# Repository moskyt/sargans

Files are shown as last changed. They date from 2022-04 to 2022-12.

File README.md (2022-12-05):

# Zeleznicni uzel Sargans

Firmware pro nadrazi z adventniho kalendare 2022.

## Popis funkci

navestidlo - mezi ctyrmi rezimy se prepina otacenim knofliku, vypina a zapina se stiskem tehoz
*MOC NEFUNGUJE* a priznam se, ze uplne nevim proc. je to zahadne naladovy.

hodiny: normalne ukazuji hodiny (s RTC)

LED displej - ukazuje linku a destinaci po prijezdu vagonku

vnitrni osvetleni - trvale zapnute

osvetleni koleje c. 3 - prepina se zlutym tlacitkem, navic blika pri prijezdu vagonku

reproduktor - hraje pri prijezdu vagonku

### Na koleji c.1/2

je 24V indukcni civka, rozsveci se svetylka na vagoncich

### Pri prijezdu vlaku na kolej c. 3

- rozblika se osvetleni koleje
- na LED banneru se zobrazi linka / destinace
- prehraje se prislusna zeleznicni znelka (SBB, CFF, FFS, SNCF, DB) + hlaseni

### Hlaseni

Osmnact jich odpovida skutecne odjizdejicim linkam ze Sargansu, ale jinak jsou ze 2/3 smyslena, aby bylo pokazde jine. Destinace pokryvaji siroke okoli i vzdalenejsi kouty Svycarska, je tam i par mezinarodnich vlaku. Jingle na zacatku odpovida cilove destinaci, jinak by samozrejme mela byt porad jen SBB.

Na displeji se ukaze jen linka a cil (popr. jedna nacestna stanice), v hlaseni je pak trasa podrobneji.

Do hlaseni jsou prigenerovane i nejake dalsi splechty ohledne sektoru trid, restauracniho vozu, absence rodinneho vozu a podobne.

## Hardware

Arduino Nano Every (5V)
https://docs.arduino.cc/hardware/nano-every

RFID ctecka 125 kHz RDM6300
https://www.laskakit.cz/rfid-ctecka-s-antenou-125khz-em4100-rdm6300/

LED maticovy displej 32x8 MAX7219
https://www.laskakit.cz/32x8-led-matice-s-max7219-3mm/
-- nasledne vymenen za stejny, ale sestimodulovy

Indukcni smycka na svetla na vagonky
https://www.adafruit.com/product/5141

RTC hodiny DS3231
https://www.gme.cz/modul-rtc-ds323-i2c-a-32kb-flash

Hodinovy displej TM1637
https://www.laskakit.cz/hodinovy-displej-0-36--tm1637/

LED pasky u 3. koleje - dva 12V stripy zapojene do serie (!)
SQ-300 https://www.t-led.cz/p/led-pasek-vnitrni-sq3-300-7101
ovladane pres MOSFET modul IRF520
https://www.laskakit.cz/mosfet-tlacitko--irf520--24vdc-5a/

LED pasky uvnitr - opet dva 12V stripy zapojene do serie (!)
SQ-600 https://www.t-led.cz/p/led-pasek-vnitrni-sq3-600-7301
pripojene primo

RFID karty EM4100 125 kHz
https://www.laskakit.cz/rfid-em4100-125khz-neprepisovatelna-karta/

MP3 prehravac MH2024K-24SS
https://www.laskakit.cz/audio-mini-mp3-prehravac/
logika je 3v3, takze na arduino TX - mp3 RX spojeni je 1.5k rezistor
pozor, oba gnd piny musi byt propojene

Reproduktor 3W / 4R
https://www.laskakit.cz/reproduktor-3w-4-40mm/
pripojeny na SPKR1/2 piny mp3 prehravace

### Napajeni

Spinany 5/24V zdroj Meanwell RD-65B:
https://www.czech-meanwell.cz/meanwell/RD-65B-Mean-Well-Spinany-zdroj-uzavreny-dvouhladino-d2182.htm

5V - napaji primo LED, ctecku, neopixely + Arduino pres 5V pin
-- pripojeno do patice v rohu desky

24V - napaji indukcni civku a LED pasky
-- rozvedene pres mirne predimenzovane svorkovnice
-> indukcni civka
-> vnitrni LED stripy
-> mosfet pro LED strip na 3. koleji

### Pinout / zapojeni

#### Arduino Nano Every

(usb portem nahoru)
```
SCK   SPI CLK (LED CLK)         CIPO  (NC)
3V3   (NC)                      COPI  SPI COPI (LED DATA)
AREF  (NC)                      D10~  LED CS
D14   neopixel                  D9~   (NC)
D15   rotary B                  D8/SS (NC)
D16   rotary A                  D7    (NC)
D17   rotary switch             D6~   (NC)
SDA   I2C data (RTC)            D5~   (NC)
SDC   I2C clk (RTC)             D4    rfid
D20   clock-display clk         D3~   gleis 3 strip
D21   clock-display data        D2    strip yellow switch
5V    power bus +               GND   (NC)
RST   (NC)                      RST   (NC)
GND   power bus -               RX    MP3 TX
VIN   (NC)                      TX    MP3 RX+R
```

#### DFPlayer mini

(SD slotem dolu)
```
L19 VCC               x
L20 RX -> [TX]+R      x
L21 TX -> [RX]        x
L22 x                 x
L23 x                 x
L24 SPKR1             x
L25 GND               GND
L26 SPKR2             x
```

#### Speaker

L26 -> MP3 SPKR2
L27 -> MP3 SPKR1

#### RFID EM4100 RDM6300

(popiskem a antenou dolu)
```
L35 DATA -> [D4]    R35 x
L36 x               R36 VCC -> +
L37 x               R37 GND -> -
L38 x
L39 x
                    R47 ANT
                    R48 ANT
```

#### LED
(VCC,GND,DATA,CS,CLK bila,modra,cervena,zelena,cerna)
R28 VCC  -> +
R29 GND  -> -
R30 DATA -> [COPI] cervena
R31 CS   -> [D10] zelena
R32 CLK  -> [SCK] modra

#### hodinovy displej

(VCC,GND,DATA,CLK zelena,cervena,modra,cerna)

L29 VCC  -> +
L30 GND  -> -
L31 DATA -> [D21] modra
L32 CLK  -> [D20] cerna

#### MOSFET (gleis 3 strip)

zapojeny primo do patice (soucastkami dovnitr)

L40 GND -> -
L41 VCC -> +
L42 SIG -> [D3]

#### Neopixel

(VCC,DATA,GND cervena,hneda,cerna -> hneda, bila, cerna)
L50 VCC  -> +
L51 DATA -> [D14]
L52 GND  -> -

! prodluzka -- proto ty zmeny barev

#### Rotary switch
(GND,VCC,SWITCH,A,B cerna,zelena,cervena,modra,bila)

#### RTC modul

posledni dva jsou uplne nezapojene, vorsicht

GND -> -
VCC -> +
SDA -> [SDA]
SCL -> [SCL]
xxx
xxx

#### zlute tlacitko
L54 -> [D2]
L55 -> -

### Poznamky

EIC napajeci zasuvka je pripojena pres vypinac (na L zile) na vstup AC/DC zdroje.

Micro USB vyvedeny na vnejsi stenu je primo vytazeny z arduina. Asi nejlepsi napad je vypnout 5V/24V napajeni pred pripojenim USB kabelu, i kdyz je mozne, ze to neni uplne nutne. Pri vypnuti napajeni je ovsem trochu problem, ze vsechny komponenty jsou napajeny skrz Arduino, coz neni nejzdravejsi (problem je zejmena LED displej, ktery je schopen pri maximalnim rozsviceni odberu 1500 mA). Stejne tak MP3. Ale snad to neni megaproblem.

## Software

### Poznamky

nelze pouzit MD_Parola knihovnu na LED displej, bud s necim koliduje, nebo zacne prepisovat nejakou pamet, ale jakkoli 'funguje', tak zacne zpusobovat nepochopitelne problemy zabranujici nahravani sketche...

nastaveni RTC hodin neni udelane nijak chytre, v pripade potreby se provede jednorazovym odkomentovanim dvou radku v setup()

trochu zrada je, ze jak mp3, tak rfid pouzivaji uart. vzhledem k tomu, ze nejde pouzit (snadno) dva softwarove uarty najednou, je mp3 pripojeny na hw uart (piny rx+tx), rfid pak potrebuje jen rx pin a ten je SW.

### Knihovny

boards package: megaAVR

RDM6300 - bundled

MD_MAX72XX - 3.3.0

Adafruit NeoPixel - 1.10.5

TM1637 - 1.2.0

InputDebounce - 1.6.0

Rotary - 1.0.0

DS3232RTC - 2.0.1

DFPlayer Mini Mp3 by Makuna - 1.1.0

## Nadrazni hlaseni

Adresar `ansagen` obsahuje dva seznamy `departures-actual_sargans` (skutecne vlaky ze Sargansu) a `departures-extra` (vymyslene vlaky ze Sargansu, primerene zajimave trasy pro hledani na mape), coz jsou pseudoCSV ve formatu LINKA | TRASA | HLASENI | JINGLE. O dalsi postup se staraji rake tasky:

### timetable

Generuje `departures.json`, ktery obsahuje uz konkretne pripraveny 48-prvkovy dataset pro jednotlive vagonky.

Texty jsou ve variante `text` pro displej a `voice` pro text-to-speech syntetizer (format SSML).

Jingle je nazev znelky, viz `ansagen/resources/jingles/*.mp3` -- pozor, ffmpeg si s nimi neporadil, pokud to nebylo 44kHz. Ale jiste by to slo poladit, kdyby si nekdo ffmpeg poradne nastudoval...

```
  "0001": { # ID
    "train": { # oznaceni vlaku
      "text": "EC 193",
      "voice": "EuroCity 193"
    },
    "destination": { # trasa
      "text": "Memmingen, München Hbf",
      "voice": "Sankt Margarethen, Bregenz, Memmingen, Buchloe, München Hauptbahnhof"
    },
    "jingle": "db", # znelka
    "departure": [ # cas odjezdu H:M
      13,
      27
    ],
    "extras": [
      "Erste klasse Sektoren A und B, Zweite klasse sektoren B, C, D, E, F und G",
      "<lang xml:lang=\"fr-FR\">Restaurant</lang> Sektor B"
    ]
  },
```

### arduino

Generuje `sargans-arduino/destinations.h`, sadu retezcu pro LED banner.

### synth

Generuje MP3 hlaseni v adresari `ansagen/mp3`. Postup je nasledujici:
* sestaveni textu hlaseni
* synteza hlasu -- Amazon Polly (AWS)
* konverze na mp3 (soubory generovane primo polly nejak neprochazely pres ffmpeg)
* spojeni s prislusnym jinglem -- ffmpeg
* pridani reverb efektu -- ffmpeg

Je potreba mit nakonfigurovany AWS CLI, resp. vygenerovany konfigurak (pomoci `aws configure` nebo rucne).

## Jak to otevrit

1) k zakladne je pevne pripojena mala cast s napajeci zasuvkou

2) cela boudicka je pripevnena k zasuvce pouze dvema vruty zboku, jinak je to tam vlastne jen polozene -- je to ale sestavene dost na treni k tem vnejsim hranolkum podel sten, tak by to nemelo vadit

3) dreveny L-profil se zlutym tlacitkem a rotary switchem je ke stenam pripevnen opet dvema vruty

4) proskleny strop jde snadno vyndat. ano, je problem, ze az prilis snadno, drazky jsou moc hluboke, takze se to da shodit dovnitr. nejspis by stalo za to pridat nejake zajisteni na ten dil s tlacitky, ale zjistil jsem to uz moc pozde.

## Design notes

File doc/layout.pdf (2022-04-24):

# ARDUINO

5V in

USB

MP3

rotary

yellow btn

red btn

## MOSFET

## RFID

LED

neopixel

clock RFID

RTC

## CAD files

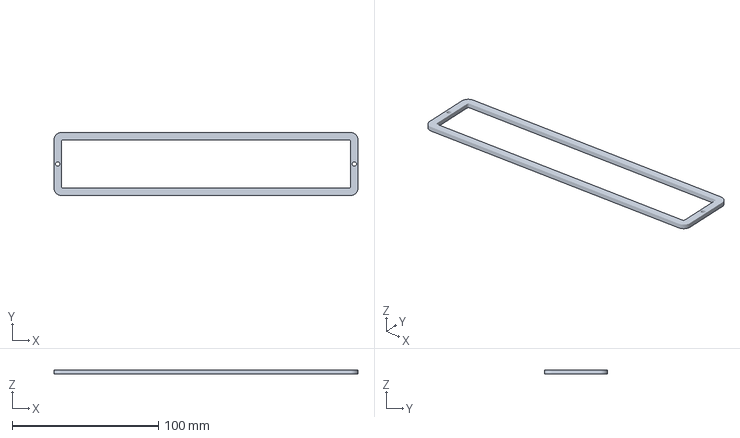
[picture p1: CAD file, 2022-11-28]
3d/led_bracket.3mf
208.0 x 43.0 x 3.00 mm

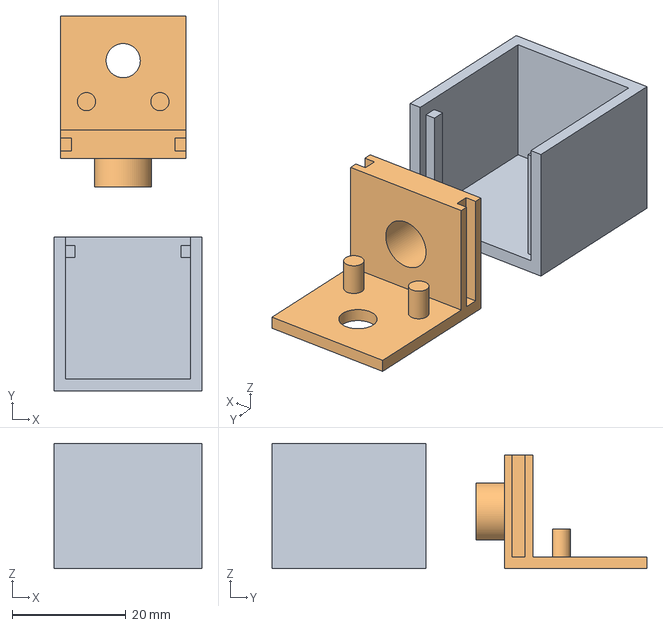
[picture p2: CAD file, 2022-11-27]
3d/semaphore.3mf
26.0 x 65.8 x 22.0 mm
semaphore.stl_1
semaphore.stl_2

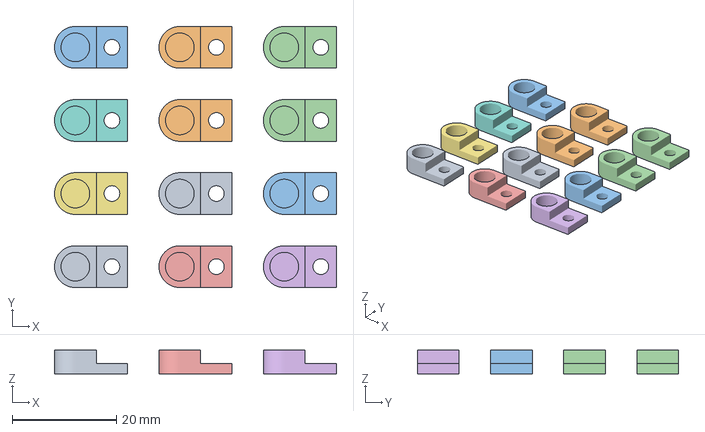
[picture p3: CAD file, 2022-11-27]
3d/led_holder.3mf
54.0 x 50.0 x 4.50 mm

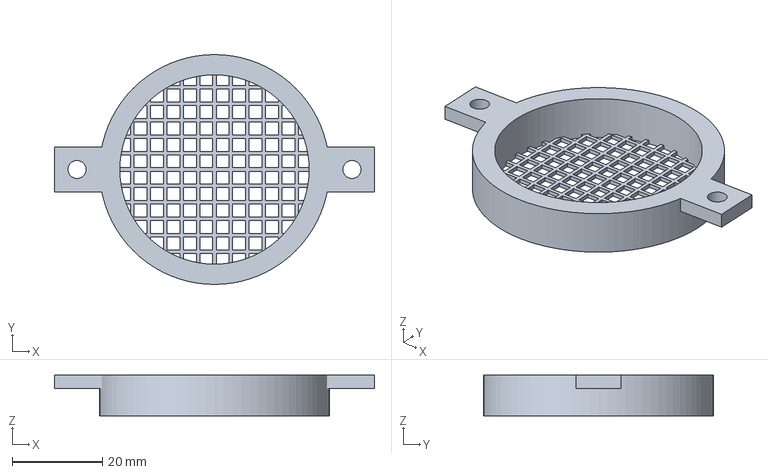
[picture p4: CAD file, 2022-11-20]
3d/speaker.3mf
71.0 x 51.0 x 9.00 mm

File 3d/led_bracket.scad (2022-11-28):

include <bosl2/std.scad>

$fn = 80;

eps = 0.1;

t = 3;
rim = 5;
inner_w = 198;
inner_h = 33;


difference() {
    cuboid([inner_w+2*rim, inner_h+2*rim, t], anchor = BOTTOM, rounding = rim, edges = [FWD+LEFT,FWD+RIGHT,BACK+LEFT,BACK+RIGHT]);
    down(eps) {
        cuboid([inner_w, inner_h, t+2*eps], anchor = BOTTOM, rounding = rim/4, edges = [FWD+LEFT,FWD+RIGHT,BACK+LEFT,BACK+RIGHT]);
        xcopies(inner_w+rim, 2)
        zcyl(l = t+2*eps, d = 3, anchor = BOTTOM);
    }
}

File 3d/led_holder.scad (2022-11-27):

include <bosl2/std.scad>

$fn = 80;

eps = 0.1;

plate_t = 2;
hole_t = 3.5;
hole_d = 5.5;
plate_d = 8;
screw_d = 3;
tab_w = 6;

difference() {
    union() {
        zcyl(plate_t/2 + hole_t, d = plate_d, anchor = BOTTOM);
        right(plate_d/4)
        cuboid([plate_d/2,plate_d,plate_t/2+hole_t],anchor=BOTTOM);
        cuboid([plate_d/2+tab_w,plate_d,plate_t],anchor=BOTTOM+LEFT);
    }
    up(plate_t/2)
    zcyl(hole_t + eps, d = hole_d, anchor = BOTTOM);
    right(plate_d/2 + tab_w/2)
    down(eps)
    zcyl(plate_t + 2*eps, d = screw_d, anchor = BOTTOM);
}

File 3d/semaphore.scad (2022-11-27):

include <bosl2/std.scad>

$fn = 80;

mx_hole_d = 3.3;
mx_hole_s = 9.5;
mx_led_d = 4.6;
mx_hole_h = 0.8;
mx_led_h = 7.3;
mx_total_h = 12.4;


eps = 0.1;

post_d = 10;
channel_d = 8;
post_h = 5;

block_w = 22;
nub_h = 5;
diode_hole_h = nub_h + 7.2;
block_t = 2;
nub_d = 3.2;
nub_spacing = 12.9;
diode_d = 6;

base_t = 5;
base_d = 20;

box_t = 2;
box_h = 25;

groove_d = 2;
groove_eps = 0.2;


back(-50)
color("red") down(base_t)
union() {
difference() {
fwd(box_t/2)
cuboid([block_w + 2*box_t,base_d + box_t, box_h+box_t], anchor=BOTTOM);
down(eps)
fwd(-eps)
cuboid([block_w,base_d, box_h], anchor=BOTTOM);
}
fwd(block_t)
up(base_t/2) {
    xcopies(block_w-groove_d+2*groove_eps,2)
    cuboid([groove_d-groove_eps,base_d,base_t/2-2*groove_eps]);
}
}

color("yellow")
difference() {
union(){
back(base_d/2) {
cuboid([block_w, block_t, box_h-base_t], anchor = BOTTOM + BACK);

up(nub_h)
fwd(block_t)
xcopies(nub_spacing,2)
ycyl(5,d=nub_d,anchor=BACK);
}
cuboid([block_w,base_d,base_t], anchor=TOP);
down(base_t)
zcyl(post_h, d=post_d, anchor=TOP);
}

up(eps)
zcyl(1000,d=channel_d,anchor=TOP);

up(diode_hole_h)
back(base_d/2)
ycyl(4*block_t,d=diode_d);

fwd(block_t+groove_eps)
down(base_t/2) {
    xcopies(block_w-groove_d+2*groove_eps,2)
    cuboid([groove_d+groove_eps,base_d+2*groove_eps,base_t/2-groove_eps]);
}


}

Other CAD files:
3d/speaker.scad
3d/led_bracket.stl
3d/led_holder.stl
3d/semaphore.stl
3d/speaker.stl

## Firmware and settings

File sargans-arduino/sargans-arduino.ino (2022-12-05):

#include <Arduino.h>
#include <MD_MAX72xx.h>
#include <TM1637Display.h>
#include <Adafruit_NeoPixel.h>
#include <InputDebounce.h>
#include <Rotary.h>
#include <DS3232RTC.h>
#include <SoftwareSerial.h>
#include <DFMiniMp3.h>

// bundled libraries
#define RDM6300_SOFTWARE_SERIAL
#include "rdm6300.h"

#include "destinations.h"

// debouncing delay for buttons in ms
const int button_debounce_delay = 20;
const int strip_blink_period = 10;
const int strip_blink_count = 10;

// led settings
#define N_LED_BLOCKS 6
#define SCROLL_DELAY 8
#define CHAR_SPACING 1

// max intensity of neopixel (signal)
const int neo_intensity = 20;

// RTC CLOCK: I2C
// LED DISPLAY: SPI (+CS)
const int pin_led_cs = 10;
// OTHER PINS
const int pin_strip_switch = 2;
const int pin_strip = 3; // pwm needed
const int pin_rdm6300 = 4;
const int pin_mp3_rx = 9;
const int pin_mp3_tx = 8;
const int pin_neopixel = 14;
const int pin_rotary_switch = 17;
const int pin_rotary_a = 15;
const int pin_rotary_b = 16;
const int pin_clockdisplay_clk = 20;
const int pin_clockdisplay_data = 21;


// RFID reader
Rdm6300 rdm6300;
// LED banner -- unfortunately, PAROLA cannot be used (insane mmry requirements)
MD_MAX72XX mx = MD_MAX72XX(MD_MAX72XX::FC16_HW, pin_led_cs, N_LED_BLOCKS);
// neopixel
Adafruit_NeoPixel pixels(1, pin_neopixel, NEO_GRB + NEO_KHZ800);
// 4-digit clock display
TM1637Display clock_display(pin_clockdisplay_clk, pin_clockdisplay_data);
// RTC
DS3232RTC rtc;

// rotary
Rotary rotary = Rotary(pin_rotary_a, pin_rotary_b);
InputDebounce rotary_button;
InputDebounce strip_button;

const int n_wagons = 48;
const uint32_t wagon_uids[n_wagons] = {
  361829,
  337311,
  343835,
  228613,
  228912,
  235002,
  250535,
  345008,
  252786,
  365067,

  355662,
  344216,
  344639,
  341953,
  339081,
  364832,
  258877,
  322125,
  203792,
  338900,

  566517,
  348127,
  329005,
  451390,
  290408,
  267758,
  186263,
  473183,
  911862,
  417940,
  
  477636,
  279181,
  // bacha prohazuju spatne nalepeny destinace 33-34, nutno otestovat
  285480, //451356,
  451356, //285480,
  293895,
  248222,
  486233,
  187191,
  342310,
  359534,
  
  273863,
  320530,
  504735,
  562113,
  538614,
  553631,
  413229,
  273606
};

#define BUF_SIZE  75
char message[BUF_SIZE] = "Sargans";

class Mp3Notify;
typedef DFMiniMp3<HardwareSerial, Mp3Notify> DfMp3;

// MP3 player notifier
class Mp3Notify {
public:
  static void OnError(DfMp3& mp3,uint16_t errorCode)
  {
    // see DfMp3_Error for code meaning
    Serial.println();
    Serial.print("MP3 com Error ");
    Serial.println(errorCode);
  }
  static void OnPlayFinished(DfMp3& mp3, DfMp3_PlaySources source, uint16_t track)
  {
    Serial.print("Play finished for #");
    Serial.println(track);
  }
  static void OnPlaySourceOnline(DfMp3& mp3,DfMp3_PlaySources source) { }
  static void OnPlaySourceInserted(DfMp3& mp3,DfMp3_PlaySources source) { }
  static void OnPlaySourceRemoved(DfMp3& mp3,DfMp3_PlaySources source) { }
};

DfMp3 mp3(Serial1);

// volume range is (0-30)
const int mp3_volume = 26;

int previous_wagon = -1;
unsigned long previous_wagon_read_time;

const int signal_mode_count = 4;
const int signal_mode_multiplier = 6;
enum signal_mode {SIG_GREEN, SIG_RED, SIG_ORANGE_BLINK, SIG_BLUE_BLINK};
signal_mode signal = SIG_RED;
bool signal_enabled = false;

bool strip_enabled = false;

int strip_blink_countdown = 0;

void setup()
{
  Serial.begin(115200);
  while (!Serial);  // wait for the serial port

  Serial.println(F("Hello from Sargans!"));

  // --- init neopixel (traffic signal)
  Serial.println(F("Init neopixel..."));
  pixels.begin();
  pixels.clear();
  pixels.setPixelColor(0, pixels.Color(0, neo_intensity, 0));
  pixels.show();

  // --- init pins not handled separately
  pinMode(pin_strip, OUTPUT);
  pinMode(pin_rdm6300, INPUT_PULLUP);

  // --- init RFID
  Serial.println(F("Init RFID..."));
  rdm6300.begin(pin_rdm6300);

  // change init signal to blue
  pixels.setPixelColor(0, pixels.Color(0, 0, neo_intensity));
  pixels.show();

  // --- init LED banner
  Serial.println(F("Init banner..."));
  mx.begin();
  mx.control(MD_MAX72XX::INTENSITY, 1); // Use a value between 0 and 15 for brightness
  printText(0, N_LED_BLOCKS-1, message);
  mx.setShiftDataInCallback(scrollDataSource);
  mx.setShiftDataOutCallback(scrollDataSink);

  // setScrollMessage(message);

  // --- init clock display
  Serial.println(F("Init clock..."));
  clock_display.setBrightness(0x02);
  uint8_t data[4];
  data[0] = clock_display.encodeDigit(9);
  data[1] = clock_display.encodeDigit(3);
  data[2] = clock_display.encodeDigit(0);
  data[3] = clock_display.encodeDigit(2);
  clock_display.setSegments(data);

  // --- init RTC
  Serial.println(F("Init RTC..."));
  rtc.begin();

  // --- set RTC time
  // this is a super-not-nice way to handle this. just set it and uncomment here.
  // might not be needed anymore!
  // Serial.println(F("Set RTC to fixed value..."));
  // setTime( 13, 51,  0, 29, 11, 2022);   // H M S , D M Y
  // rtc.set(now());
  Serial.println(F("Get RTC time..."));
  tmElements_t tm;
  rtc.read(tm);
  Serial.print(tm.Hour);
  Serial.print(F(":"));
  Serial.print(tm.Minute);
  Serial.print(F(":"));
  Serial.println(tm.Second);

  // --- init MP3
  Serial.println(F("Init MP3..."));

  mp3.begin();

  uint16_t volume = mp3.getVolume();
  Serial.print(F("original volume: "));
  Serial.println(volume);
  mp3.setVolume(mp3_volume);
  volume = mp3.getVolume();
  Serial.print(F("new volume: "));
  Serial.println(volume);
  if (volume == 0) {
    mp3.begin();
  }

  uint16_t count = mp3.getTotalTrackCount(DfMp3_PlaySource_Sd);
  Serial.print(F("number of mp3 files: "));
  Serial.println(count);

  // --- init rotary switch
  Serial.println(F("Init rotary..."));
  pinMode(pin_rotary_a, INPUT);
  pinMode(pin_rotary_b, INPUT);
  rotary.setChangedHandler(rotate);

  // --- init the buttons
  rotary_button.registerCallbacks(rotary_button_pressedCallback, NULL, NULL, NULL);
  rotary_button.setup(pin_rotary_switch, button_debounce_delay, InputDebounce::PIM_INT_PULL_UP_RES);
  strip_button.registerCallbacks(strip_button_pressedCallback, NULL, NULL, NULL);
  strip_button.setup(pin_strip_switch, button_debounce_delay, InputDebounce::PIM_INT_PULL_UP_RES);

  Serial.println(F("Init done."));
}

void loop() {
  unsigned long now = millis();
  bool blink = true;

  // --- process the LED banner display
  scrollText();

  // --- process the rotary encoder
  rotary.loop();

  // --- process the buttons
  rotary_button.process(now);
  strip_button.process(now);

  // --- process RFID
  [&] {
    if (!rdm6300.get_new_tag_id()) return;
    const uint32_t uid = rdm6300.get_tag_id();
    Serial.print(F("Read RFID "));
    Serial.print(uid, HEX);
    int current_wagon = -1;
    for (int i = 0; i < n_wagons; ++i) {
      if (wagon_uids[i] == uid) {
        current_wagon = i;
        break;
      }
    }
    Serial.print(F(" -> wagon "));
    Serial.println(current_wagon);

    const unsigned long now = millis();

    if (current_wagon == -1) return;
    if (previous_wagon == -1) {
      previous_wagon = current_wagon;
      previous_wagon_read_time = now;
      return;
    }

    const bool wagon_changed = current_wagon != previous_wagon;
    previous_wagon = current_wagon;

    // Sometimes the RFID reader starts reading the same ID in a loop. E.g.,
    // this always happens when the reader boots up with card on it. This logic
    // will only process an ID if there's minimum 2 seconds between reading the
    // same ID or the ID has changed since the last read.
    const bool should_play = [&] {
      if (wagon_changed) return true;
      const unsigned long time_since_last_read = now - previous_wagon_read_time;
      previous_wagon_read_time = now;
      return time_since_last_read > 2000;
    }();

    if (!should_play) return;

    Serial.print(F(" => printing message "));
    Serial.println(destinations[current_wagon]);

    setScrollMessage(destinations[current_wagon]);
    strip_blink_countdown = strip_blink_period * strip_blink_count;
    mp3.playMp3FolderTrack(current_wagon+1);
  }();

  // --- show the clock + init the blink flag
  tmElements_t tm;
  rtc.read(tm);
  blink = (tm.Second % 2 > 0);
  clock_display.showNumberDecEx(tm.Hour * 100 + tm.Minute, blink ? 0b01000000 : 0, true);

  // --- show the signals
  if (!signal_enabled) {
    pixels.setPixelColor(0, pixels.Color(0, 0, 0));
  } else
  if (signal == SIG_RED) {
    pixels.setPixelColor(0, pixels.Color(neo_intensity, 0, 0));
  } else
  if (signal == SIG_GREEN) {
    pixels.setPixelColor(0, pixels.Color(0, neo_intensity, 0));
  }
  if (signal == SIG_BLUE_BLINK) {
    if (blink)
      pixels.setPixelColor(0, pixels.Color(0, 0, neo_intensity));
    else
      pixels.setPixelColor(0, pixels.Color(neo_intensity, neo_intensity, neo_intensity));
  }
  if (signal == SIG_ORANGE_BLINK) {
    if (blink)
      pixels.setPixelColor(0, pixels.Color(neo_intensity, neo_intensity, 0));
    else
      pixels.setPixelColor(0, pixels.Color(0, 0, 0));
  }
  pixels.show();

  // --- handle the led strip
  if (strip_blink_countdown > 0) {
    strip_blink_countdown--;
    int m = strip_blink_countdown / strip_blink_period;
    if (m % 2 == 0)
      analogWrite(pin_strip, 250);
    else
      analogWrite(pin_strip, 0);
  } else {
    if (strip_enabled)
      analogWrite(pin_strip, 50);
    else
      analogWrite(pin_strip, 0);
  }

  // --- poll MP3
  mp3.loop();

  delay(10);
}

void rotary_button_pressedCallback(uint8_t pinIn) {
  Serial.print(F("Rotary switch (signal) pressed -> "));
  signal_enabled = !signal_enabled;
  Serial.println(signal_enabled);
}

void strip_button_pressedCallback(uint8_t pinIn) {
  Serial.print(F("Yellow switch (strip) pressed -> "));
  strip_enabled = !strip_enabled;
  Serial.println(strip_enabled);
}

// on rotary change
void rotate(Rotary& r) {
  int rpos = r.getPosition();
  signal = (rpos / 2) % signal_mode_count;
  Serial.print(F("Rotated the encoder to pos = "));
  Serial.print(rpos);
  Serial.print(F(" / signal = "));
  Serial.println(signal);
}

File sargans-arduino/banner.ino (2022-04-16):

enum { NONE, LOAD_CHAR, SHOW_CHAR, BETWEEN_CHAR } scroll_state = NONE;
uint8_t* scroll_ptr = NULL;

void setScrollMessage(uint8_t* msg) {
  scroll_ptr = msg;
  scroll_state = LOAD_CHAR;
}

void scrollDataSink(uint8_t dev, MD_MAX72XX::transformType_t t, uint8_t col) {}

uint8_t scrollDataSource(uint8_t dev, MD_MAX72XX::transformType_t t) {
  static uint8_t  curLen, showLen;
  static uint8_t  cBuf[15];
  uint8_t colData = 0;    // blank column is the default

  if (!scroll_ptr) {
    scroll_state = NONE;
    return(0);
  }

  switch(scroll_state) {
    case NONE:
      return(0);
    case LOAD_CHAR: // Load the next character from the font table

      if (*scroll_ptr == '\0') {
        // end of message
        scroll_ptr = NULL;
        scroll_state = NONE;
        return(0);
      }

      showLen = mx.getChar(*scroll_ptr++, sizeof(cBuf)/sizeof(cBuf[0]), cBuf);
      curLen = 0;
      scroll_state = SHOW_CHAR;

      // !! deliberately fall through to next state to start displaying

    case SHOW_CHAR: // display the next part of the character
      colData = cBuf[curLen++];
      if (curLen == showLen) {
        showLen = CHAR_SPACING;
        curLen = 0;
        scroll_state = BETWEEN_CHAR;
      }
      break;

    case BETWEEN_CHAR: // display inter-character spacing (blank columns)
      colData = 0;
      curLen++;
      if (curLen == showLen)
        scroll_state = LOAD_CHAR;
      break;

    default:
      scroll_state = LOAD_CHAR;
  }

  return(colData);
}

 void scrollText(void)
{
  static uint32_t prevTime = 0;

  // Is it time to scroll the text?
  if (millis() - prevTime >= SCROLL_DELAY)
  {
    mx.transform(MD_MAX72XX::TSL);  // scroll along - the callback will load all the data
    prevTime = millis();      // starting point for next time
  }
}


void printText(uint8_t modStart, uint8_t modEnd, char *pMsg)
// Print the text string to the LED matrix modules specified.
// Message area is padded with blank columns after printing.
{
  uint8_t   state = 0;
  uint8_t   curLen;
  uint16_t  showLen;
  uint8_t   cBuf[8];
  int16_t   col = ((modEnd + 1) * COL_SIZE) - 1;

  mx.control(modStart, modEnd, MD_MAX72XX::UPDATE, MD_MAX72XX::OFF);

  do     // finite state machine to print the characters in the space available
  {
    switch(state)
    {
      case 0: // Load the next character from the font table
        // if we reached end of message, reset the message pointer
        if (*pMsg == '\0')
        {
          showLen = col - (modEnd * COL_SIZE);  // padding characters
          state = 2;
          break;
        }

        // retrieve the next character form the font file
        showLen = mx.getChar(*pMsg++, sizeof(cBuf)/sizeof(cBuf[0]), cBuf);
        curLen = 0;
        state++;
        // !! deliberately fall through to next state to start displaying

      case 1: // display the next part of the character
        mx.setColumn(col--, cBuf[curLen++]);

        // done with font character, now display the space between chars
        if (curLen == showLen)
        {
          showLen = CHAR_SPACING;
          state = 2;
        }
        break;

      case 2: // initialize state for displaying empty columns
        curLen = 0;
        state++;
        // fall through

      case 3:  // display inter-character spacing or end of message padding (blank columns)
        mx.setColumn(col--, 0);
        curLen++;
        if (curLen == showLen)
          state = 0;
        break;

      default:
        col = -1;   // this definitely ends the do loop
    }
  } while (col >= (modStart * COL_SIZE));

  mx.control(modStart, modEnd, MD_MAX72XX::UPDATE, MD_MAX72XX::ON);
}

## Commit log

2022-04-24 add separate rdm6300 test code. upgraded to 6-block led.
2022-04-24 use hw+sw uart. readme. mp3 tester
2022-11-20 3d speaker
    [speaker.3mf, speaker.scad, speaker.stl]
2022-11-22 more models
    [led_holder.3mf, led_holder.scad, led_holder.stl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]
2022-11-27 updating to the new iteration
    [led_holder.3mf, led_holder.scad, led_holder.stl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]
2022-11-28 led bracket, more dox
    [led_bracket.3mf, led_bracket.scad, led_bracket.stl]
